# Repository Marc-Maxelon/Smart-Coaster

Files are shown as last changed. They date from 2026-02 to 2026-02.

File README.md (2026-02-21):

# Smart Coaster: The Future of Service Begins on the Table

Welcome to the official repository for the **Smart Coaster**, an intelligent IoT solution designed to revolutionize the gastronomy industry by staying one step ahead of guest needs.

## 🚀 Business Pitch: Why Smart Coaster?
The gastronomy sector currently faces rising personnel costs, a shortage of skilled labor, and high service pressure. Traditional manual beverage monitoring is time-consuming and error-prone, often leading to empty glasses and lost revenue.

Our Smart Coaster transforms this process. By utilizing **weight-based fill-level detection** and **RFID identification**, it informs service staff in real-time when a guest needs a refill—before the guest even notices.

**Key Value Propositions:**
* **Boost Revenue:** Minimize wait times to maximize beverage sales.
* **Staff Relief:** Reduce manual control walks, allowing staff to focus on high-quality guest interaction.
* **Enhanced Experience:** Ensure guests never sit in front of an empty glass, increasing satisfaction and loyalty.

---

## 🛠 Technical Architecture
The system is built on a robust, interdisciplinary stack that combines precise sensor technology with cloud-based communication.

### System Overview
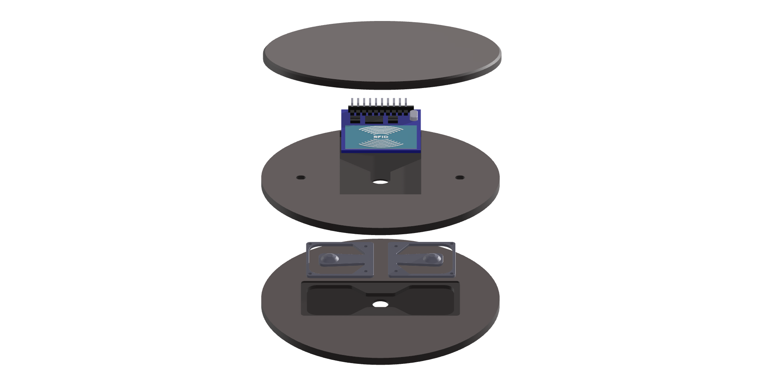
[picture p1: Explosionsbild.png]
Smart Coaster System Components

*Figure 1: Exploded view of the Smart Coaster's mechanical and electronic assembly.*

1. **Sensing:** A **KERN CK 10-Y4 Load Cell** measures the precise weight of the glass.
2. **Identification:** An **NXP MFRC-522 RFID Module** identifies the specific glass or drink type via passive tags.
3. **Processing:** An **Arduino Nano ESP32 (ESP32-S3)** serves as the central brain, processing signals and classifying states (Full, Half-full, Empty).
4. **Signal Conditioning:** The **HX711 24-bit ADC** amplifies the tiny millivolt signals from the load cell for digital processing.
5. **Connectivity:** Data is transmitted via the **MQTT protocol** to a central dashboard.

---

## 📊 Feature Highlights
* **Intelligent Logic:** Software-side tolerance buffers (15g) prevent data "flickering" caused by table vibrations or drafts.
* **Real-time Dashboard:** A GUI displays the exact milliliter fill level and triggers an "Empty Warning" when the level drops below 10%.
* **Automatic Calibration:** The system features an interactive startup calibration to ensure high measurement accuracy.

Marketing Poster
*Figure 2: The Smart Coaster concept: "Smarter Service begins on the table".*

---

## 👥 The Team
This project was developed at **Hochschule Düsseldorf (HSD)** for the **Smart Systems II** module under Professor Dr.-Ing. Protogerakis.

| Name | Role |
| :--- | :--- |
| **Maxim Speczyk** | Project Lead & Software |
| **Bünyamin Budak** | Software & Visualisation |
| **Cecilia Koehn** | Design, Hardware Concept & Marketing |
| **Clemens Birmes** | Hardware Lead & 3D Construction |
| **Marouane Grar** | System Integration & Components |
| **Marc Maxelon** | Documentation & Quality Assurance |

---

## 📈 Future Roadmap
* **Miniaturization:** Integration of all components onto a custom PCB.
* **Energy Autonomy:** Moving from wired power to rechargeable batteries with inductive charging.
* **Visual Feedback:** Implementation of an LED ring to signal status directly to the guest.
* **Payment Integration:** Enabling the coaster to serve as a direct interface for mobile payments.

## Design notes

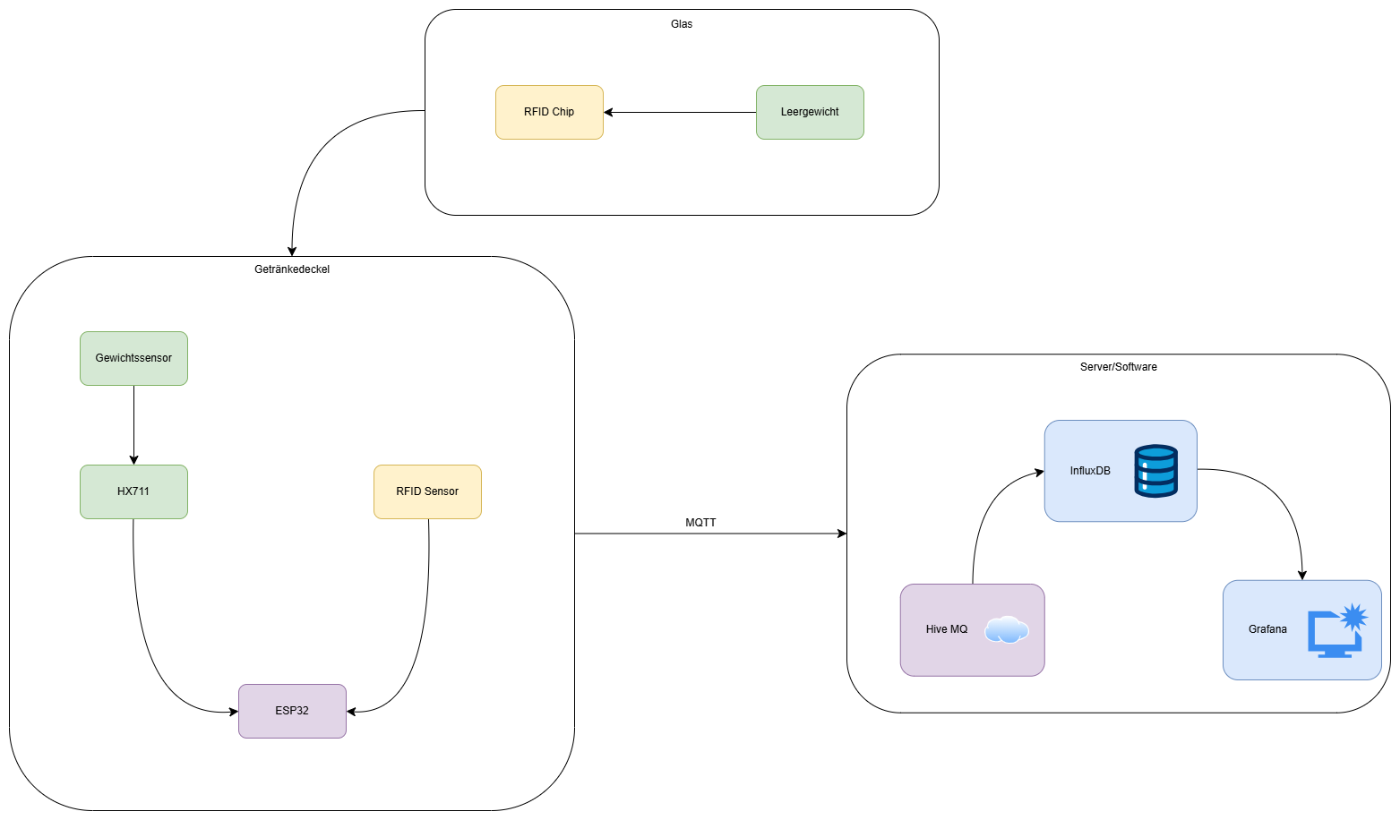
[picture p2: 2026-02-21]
Diagramme/Konzept.png

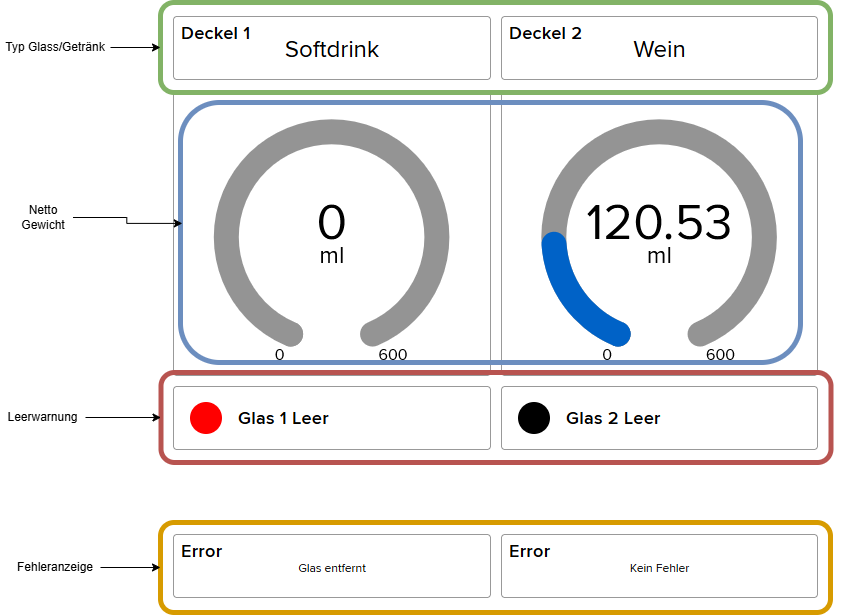
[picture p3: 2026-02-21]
Diagramme/GUI.png

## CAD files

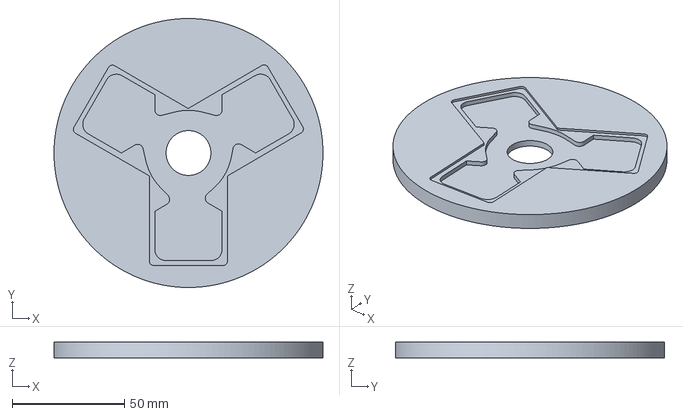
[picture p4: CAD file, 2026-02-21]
3D-Models/Prototyp/3_Zeller.3mf
120.0 x 120.0 x 7.00 mm

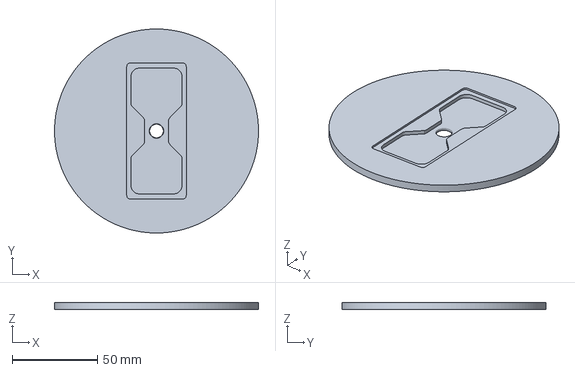
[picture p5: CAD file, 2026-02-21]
3D-Models/V_2/Untersetzer.V_2.3mf
120.0 x 120.0 x 4.00 mm

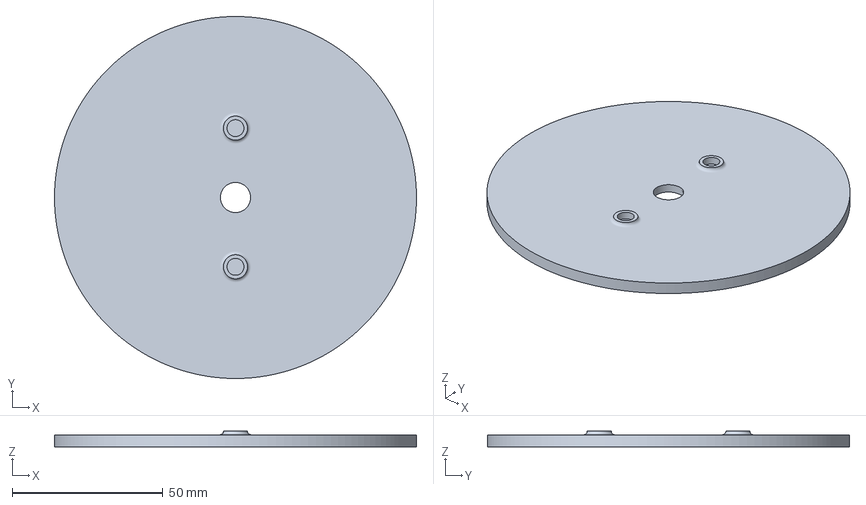
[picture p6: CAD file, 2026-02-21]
3D-Models/V_2/Deckel-Unterseite.V_2.3mf
120.0 x 120.0 x 5.20 mm

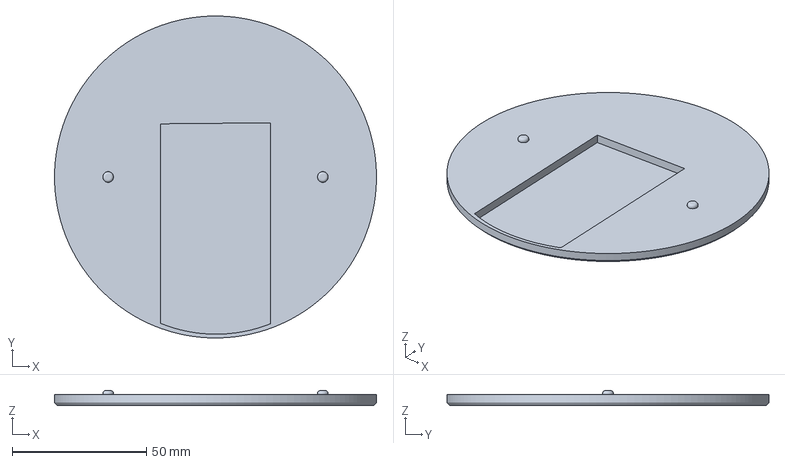
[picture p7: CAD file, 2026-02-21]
3D-Models/V_2/Deckel-Oberteil.V_2.3mf
120.0 x 120.0 x 5.50 mm

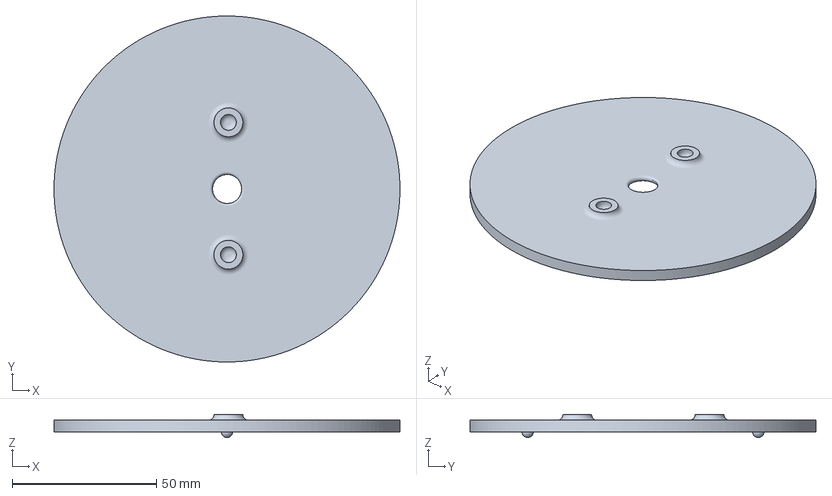
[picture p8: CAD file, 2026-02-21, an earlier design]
3D-Models/V_1/Deckel-Unterseite.3mf
120.0 x 120.0 x 8.00 mm

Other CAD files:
3D-Models/V_1/Untersetzer.3mf
3D-Models/V_1/Deckel-Oberteil.3mf
3D-Models/Prototyp/3-Zeller.stl
3D-Models/V_1/Deckel-Oberteil.stl
3D-Models/V_1/Deckel-Unterseite.stl
3D-Models/V_1/Untersetzer.stl
3D-Models/V_2/Deckel-Oberteil.V_2.stl
3D-Models/V_2/Deckel-Unterseite.V_2.stl
3D-Models/V_2/Untersetzer.V_2.stl

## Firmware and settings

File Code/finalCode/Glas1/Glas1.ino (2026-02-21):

#define WLAN_SSID      
#define WLAN_PASS  

#include <WiFi.h>
#include "Adafruit_MQTT.h"
#include "Adafruit_MQTT_Client.h"
#include <SPI.h>
#include <MFRC522.h>
#include "HX711.h"

#define AIO_SERVER      "io.adafruit.com"
#define AIO_SERVERPORT  1883
#define AIO_USERNAME    ""
#define AIO_KEY         ""

const int LOADCELL_DOUT_PIN = D2; 
const int LOADCELL_SCK_PIN = D3;
#define SS_PIN  D10
#define RST_PIN D9

WiFiClient client;
Adafruit_MQTT_Client mqtt(&client, AIO_SERVER, AIO_SERVERPORT, AIO_USERNAME, AIO_KEY);
Adafruit_MQTT_Publish feedGlas = Adafruit_MQTT_Publish(&mqtt, AIO_USERNAME "/feeds/glas-1");
Adafruit_MQTT_Publish feedGewicht = Adafruit_MQTT_Publish(&mqtt, AIO_USERNAME "/feeds/gewicht-1");
Adafruit_MQTT_Publish feedError = Adafruit_MQTT_Publish(&mqtt, AIO_USERNAME "/feeds/error");
Adafruit_MQTT_Publish feedEmpty = Adafruit_MQTT_Publish(&mqtt, AIO_USERNAME "/feeds/leer-warnung");

HX711 scale;
MFRC522 mfrc522(SS_PIN, RST_PIN);

// --- VARIABLEN (Alles in Gramm [g]) ---
float glassWeight = 0.0; 
float maxLiquidWeight = 0.0; 
String lastDrinkName = "";
bool lastEmptyState = false; 
bool errorActive = false;

unsigned long lastReportTime = 0;
const long reportInterval = 5000; 
const int PAGE_ADDR = 4;
const float TOLERANCE = 15.0; // 15g Toleranz gegen Rauschen

void MQTT_connect();
void waitForInput();

void setup() {
  Serial.begin(115200);
  delay(2000);

  WiFi.begin(WLAN_SSID, WLAN_PASS);
  while (WiFi.status() != WL_CONNECTED) {
    delay(500);
    Serial.print(".");
  }
  Serial.println("\nWiFi connected");

  scale.begin(LOADCELL_DOUT_PIN, LOADCELL_SCK_PIN);
  SPI.begin();
  mfrc522.PCD_Init();

  // --- KALIBRIERUNG (mit 380g) ---
  Serial.println("--- KALIBRIERUNG START (Einheit: Gramm) ---");
  Serial.println("1. Waage leer lassen. Type '1' + ENTER.");
  waitForInput();
  
  scale.set_scale(); 
  scale.tare(20);
  Serial.println("Tariert.");

  Serial.println("2. Stelle genau 380g auf. Type '1' + ENTER.");
  waitForInput();
  
  long reading = scale.get_value(20); 
  float newFactor = (float)reading / 380.0; // Faktor für Gramm
  scale.set_scale(newFactor);

  Serial.print("Neuer Faktor: "); Serial.println(newFactor);
  Serial.println("System bereit...");
}

void loop() {
  MQTT_connect();

  // --- 1. RFID SCAN (Eher sporadisch / für neue Gläser) ---
  // Wir checken nur, wenn kein Glas bekannt ist oder wir ein neues erzwingen wollen
  if (mfrc522.PICC_IsNewCardPresent() && mfrc522.PICC_ReadCardSerial()) {
    byte buffer[18];
    byte size = sizeof(buffer);
    if (mfrc522.MIFARE_Read(PAGE_ADDR, buffer, &size) == MFRC522::STATUS_OK) {
      byte drinkID = buffer[0];
      String currentDrink = "";
      float currentGlassW = 0.0;
      float currentMaxL = 0.0;

      // Werte in Gramms
      if (drinkID == 1)      { currentDrink = "Softdrink"; currentGlassW = 393.0; currentMaxL = 330.0; }
      else if (drinkID == 2) { currentDrink = "Wein";      currentGlassW = 162.0; currentMaxL = 200.0; }
      else if (drinkID == 3) { currentDrink = "Bier";      currentGlassW = 180.0; currentMaxL = 250.0; }

      if (currentDrink != "" && currentDrink != lastDrinkName) {
        if (feedGlas.publish(currentDrink.c_str())) {
          lastDrinkName = currentDrink;
          glassWeight = currentGlassW;
          maxLiquidWeight = currentMaxL;
          Serial.print("Glas erkannt: "); Serial.println(lastDrinkName);
          
          if (errorActive) {
            feedError.publish("Kein Fehler");
            errorActive = false;
          }
        }
      }
    }
    mfrc522.PICC_HaltA();
    mfrc522.PCD_StopCrypto1();
  }

  // --- 2. MESSUNG & LOGIK ---
  if (millis() - lastReportTime > reportInterval) {
    lastReportTime = millis();

    float currentRaw = scale.get_units(10); // Gewicht in Gramm
    Serial.print("Waage Brutto: "); Serial.print(currentRaw, 1); Serial.println(" g");

    // PRÄSENZ-LOGIK: 
    // Wenn ein Glas bekannt ist, aber das Gewicht unter 75% des Leergewichts fällt -> Glas entfernt
    if (lastDrinkName != "" && currentRaw < (glassWeight * 0.75)) {
        if (!errorActive) {
          feedError.publish("Glas entfernt");
          feedEmpty.publish("false"); // Lampe aus
          errorActive = true;
          Serial.println("STATUS: Glas wurde weggenommen.");
        }
        lastDrinkName = "";
        glassWeight = 0;
    } 
    // FALLS wir ein Glas haben und das Gewicht passt:
    else if (lastDrinkName != "") {
      float liquidWeight = currentRaw - glassWeight;
      
      // Kleiner Puffer gegen Rauschen
      if (liquidWeight < TOLERANCE) liquidWeight = 0.0;

      // Senden
      Serial.print("Netto (Inhalt): "); Serial.print(liquidWeight); Serial.println(" g");
      feedGewicht.publish(liquidWeight);

      // 10% Logik
      bool isEmpty = (liquidWeight < (maxLiquidWeight * 0.10));
      if (isEmpty != lastEmptyState) {
        if (feedEmpty.publish(isEmpty ? "true" : "false")) {
          lastEmptyState = isEmpty;
        }
      }
    } 
    // FALLS kein Glas da ist und kein RFID erkannt wurde -> Error zeigen
    else if (lastDrinkName == "" && !errorActive) {
        // Wir senden den Fehler nur, wenn die Waage auch wirklich leer ist
        if (currentRaw < 50.0) { 
           feedError.publish("Kein Glas erkannt");
           errorActive = true;
        }
    }
  }
}

void waitForInput() {
  while (true) {
    if (Serial.available() > 0) {
      char c = Serial.read();
      if (c == '1') {
        while(Serial.available()) Serial.read();
        return;
      }
    }
    delay(10);
  }
}

void MQTT_connect() {
  if (mqtt.connected()) return;
  int8_t ret;
  while ((ret = mqtt.connect()) != 0) {
    mqtt.disconnect();
    delay(5000);
  }
}

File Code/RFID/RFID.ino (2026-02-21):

#include <SPI.h>
#include <MFRC522.h>

// Pins für Arduino Nano ESP32
#define SS_PIN  D10
#define RST_PIN D9

// MISO D12
// MOSI D11
// RST D13

MFRC522 mfrc522(SS_PIN, RST_PIN);

// Variable für Schreib-Modus
int writeMode = 0; // 0=Lesen, 1=Softdrink, 2=Wein, 3=Bier

// Page 4 ist der erste sichere Speicherplatz für User-Daten auf NTAG/Ultralight
const int PAGE_ADDR = 4; 

void setup() {
  Serial.begin(115200);
  delay(2000); 

  SPI.begin();        
  mfrc522.PCD_Init(); 

  Serial.println("------------------------------------------------");
  Serial.println("   NFC CHIP WRITER - GETRAENKE-SYSTEM");
  Serial.println("------------------------------------------------");
  Serial.println("BEFEHLE für den Schreibmodus:");
  Serial.println("'1' + Enter -> SCHREIBE: Softdrink (380g Glas)");
  Serial.println("'2' + Enter -> SCHREIBE: Wein      (150g Glas)");
  Serial.println("'3' + Enter -> SCHREIBE: Bier      (400g Glas)");
  Serial.println("'0' + Enter -> NUR LESEN");
  Serial.println("------------------------------------------------");
}

void loop() {
  // 1. Serielle Befehle verarbeiten
  if (Serial.available() > 0) {
    char command = Serial.read();
    if (command == '1') {
      writeMode = 1;
      Serial.println("\n[MODUS] Nächster Chip wird: SOFTDRINK");
    } else if (command == '2') {
      writeMode = 2;
      Serial.println("\n[MODUS] Nächster Chip wird: WEIN");
    } else if (command == '3') {
      writeMode = 3;
      Serial.println("\n[MODUS] Nächster Chip wird: BIER");
    } else if (command == '0') {
      writeMode = 0;
      Serial.println("\n[MODUS] Nur Lesen.");
    }
    // Buffer leeren (Enter abfangen)
    while(Serial.available()) Serial.read(); 
  }

  // 2. Prüfen ob ein Chip da ist
  if ( ! mfrc522.PICC_IsNewCardPresent()) return;
  if ( ! mfrc522.PICC_ReadCardSerial()) return;

  // --- Chip Aktion ---
  if (writeMode > 0) {
    writeDrinkToNTAG(writeMode);
    writeMode = 0; // Nach dem Schreiben zurück in Lesemodus
    Serial.println("System bereit zum Lesen.");
  } else {
    readDrinkFromNTAG();
  }

  // Karte stoppen
  mfrc522.PICC_HaltA(); 
  mfrc522.PCD_StopCrypto1();
  
  delay(1500); // Kurze Pause zur Stabilisierung
}

void readDrinkFromNTAG() {
  byte buffer[18];
  byte size = sizeof(buffer);

  MFRC522::StatusCode status = mfrc522.MIFARE_Read(PAGE_ADDR, buffer, &size);
  
  if (status != MFRC522::STATUS_OK) {
    Serial.print("Fehler beim Lesen: ");
    Serial.println(mfrc522.GetStatusCodeName(status));
    return;
  }

  byte drinkID = buffer[0]; 
  Serial.print("\n>>> Chip erkannt! ");
  
  switch(drinkID) {
    case 1:  Serial.println("Inhalt: SOFTDRINK (380g)"); break;
    case 2:  Serial.println("Inhalt: WEIN (150g)"); break;
    case 3:  Serial.println("Inhalt: BIER (400g)"); break;
    default: 
      Serial.print("Unbekannter Inhalt (ID: "); 
      Serial.print(drinkID); 
      Serial.println(")"); 
      break;
  }
}

void writeDrinkToNTAG(int drinkType) {
  byte data[4]; 
  data[0] = (byte)drinkType; // Die ID (1, 2 oder 3)
  data[1] = 0;
  data[2] = 0;
  data[3] = 0;

  Serial.print("Schreibe Daten auf Page 4... ");

  MFRC522::StatusCode status = mfrc522.MIFARE_Ultralight_Write(PAGE_ADDR, data, 4);

  if (status != MFRC522::STATUS_OK) {
    Serial.print("FEHLGESCHLAGEN: ");
    Serial.println(mfrc522.GetStatusCodeName(status));
  } else {
    Serial.println("ERFOLG!");
    Serial.print("Chip ist nun als ");
    if(drinkType == 1) Serial.println("SOFTDRINK markiert.");
    if(drinkType == 2) Serial.println("WEIN markiert.");
    if(drinkType == 3) Serial.println("BIER markiert.");
  }
}

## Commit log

2026-02-21 Diagramme & Projektplanung
    [Projektrollen & Stakeholder.xlsx]
2026-02-21 Revise README with comprehensive project details
    Expanded the README to include business pitch, technical architecture, feature highlights, team members, and future roadmap for the Smart Coaster project.
